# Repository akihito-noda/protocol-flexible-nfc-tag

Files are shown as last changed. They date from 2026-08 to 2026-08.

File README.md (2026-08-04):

# Protocol-Flexible Custom NFC Sensor Tag

Hardware design files and firmware for the sensor tag described in:

> R. Maeda and A. Noda, "Protocol-Flexible Custom NFC for Wire-Free Wearable Sensor Networks,"
> *IEEE Sensors Letters*, under review.

An NFC sensor tag whose communication protocol is defined in software rather than fixed in a
transponder IC. This repository holds the material that does not fit within the four-page limit of
the Letter. It is not a build guide; the schematic and the sources are the primary record, and
anything not stated here can be read from them.

This is a research prototype for protocol exploration. It is not optimized for power
(17 mW, battery-powered) and it does not implement, and is not interoperable with, ISO/IEC 14443.

## Contents

```
hardware/
  schematic/tag-schematic.pdf   Tag schematic, with component values
  gerber/                       Gerber and drill files for the tag PCB
firmware/
  tag_sensor/                   Tag firmware (Arduino sketch, ATmega328P)
  reader/                       Reader firmware (Arduino sketch, STM32duino)
```

No separate bill of materials is provided; the parts are on the schematic.

## Reader hardware

Commercial boards, used as supplied, so no design files are included here:

- **X-NUCLEO-NFC08A1** (STMicroelectronics), carrying an **ST25R3916B** NFC reader IC and a
  47 mm x 34 mm four-turn 13.56 MHz printed antenna
- **NUCLEO-L476RG** (STMicroelectronics) as the host

The ST25R3916B was selected for its transparent mode, which bypasses the on-chip framing and coding
and gives the host microcontroller access to the baseband signals. Its automatic antenna tuning is
not used, and apart from the register writes in `reader.ino` the IC runs with its default settings.

## Build environment

Arduino IDE 2.3.10.

**Reader.** STM32duino core 2.12.0, board Nucleo-64 with part number Nucleo L476RG, upload by mass
storage. `U(S)ART support` must be set to *Enabled (no generic 'Serial')*, because the sketch
declares its own `HardwareSerial` instances.

**Tag.** The ATmega328P runs from its internal 8 MHz RC oscillator, so the stock Arduino board list
does not cover it. We used the *ATmega328 on a breadboard (8 MHz internal clock)* definition that
Arduino distributes as `breadboard-1-6-x.zip`
(<https://www.arduino.cc/en/uploads/Tutorial/breadboard-1-6-x.zip>, described at
<https://docs.arduino.cc/built-in-examples/arduino-isp/ArduinoToBreadboard/>). It is not
redistributed here, since its licence is not stated. The instructions on that page are for an older
IDE; with IDE 2.x we had to extract the archive into the Arduino data directory
(`%LOCALAPPDATA%\Arduino15\packages\` on Windows) rather than the sketchbook `hardware` folder.
Tested on Windows only.

`TAG_NUM` in `tag_sensor.ino` sets the address of each tag and must differ between them.

## Protocol

| | |
| --- | --- |
| Carrier | 13.56 MHz |
| Reader to tag | 10% ASK |
| Tag to reader | Load modulation, on-off keying on a 1 MHz subcarrier |
| Line code | Return-to-zero, generated by expanding UART output |
| UART baud rate | 100 kbaud (50 kbaud effective after RZ) |
| Request frame | 2 bytes |
| Reply frame | 3 acceleration bytes and 1 CRC byte |
| Slot time | 1.5 ms per tag |
| Polling rate | 222 Hz per tag with three tags |

`ERR_COUNT` in `reader.ino` selects the mode: when defined, the sketch counts failed polls per tag
instead of printing samples. It is set to 1000, the value used for the packet-error-rate
measurements in the paper.

## Meander coil

400 mm x 260 mm, copper tape on a fabric substrate, divided into six sections by series capacitors.
Measured with the loop opened: L = 1.7 uH, and with 82.5 pF in series the resonance is at 13.44 MHz
with |Z11| = 6.45 ohm, Q = 22.3 and a -3 dB bandwidth of 604 kHz. The coil follows prior work cited
in the paper and is not a contribution of this repository.

## License

MIT License, see `LICENSE`. This covers the whole repository, including the hardware design files.

## Citing

See `CITATION.cff`. Please cite the Letter rather than this repository.

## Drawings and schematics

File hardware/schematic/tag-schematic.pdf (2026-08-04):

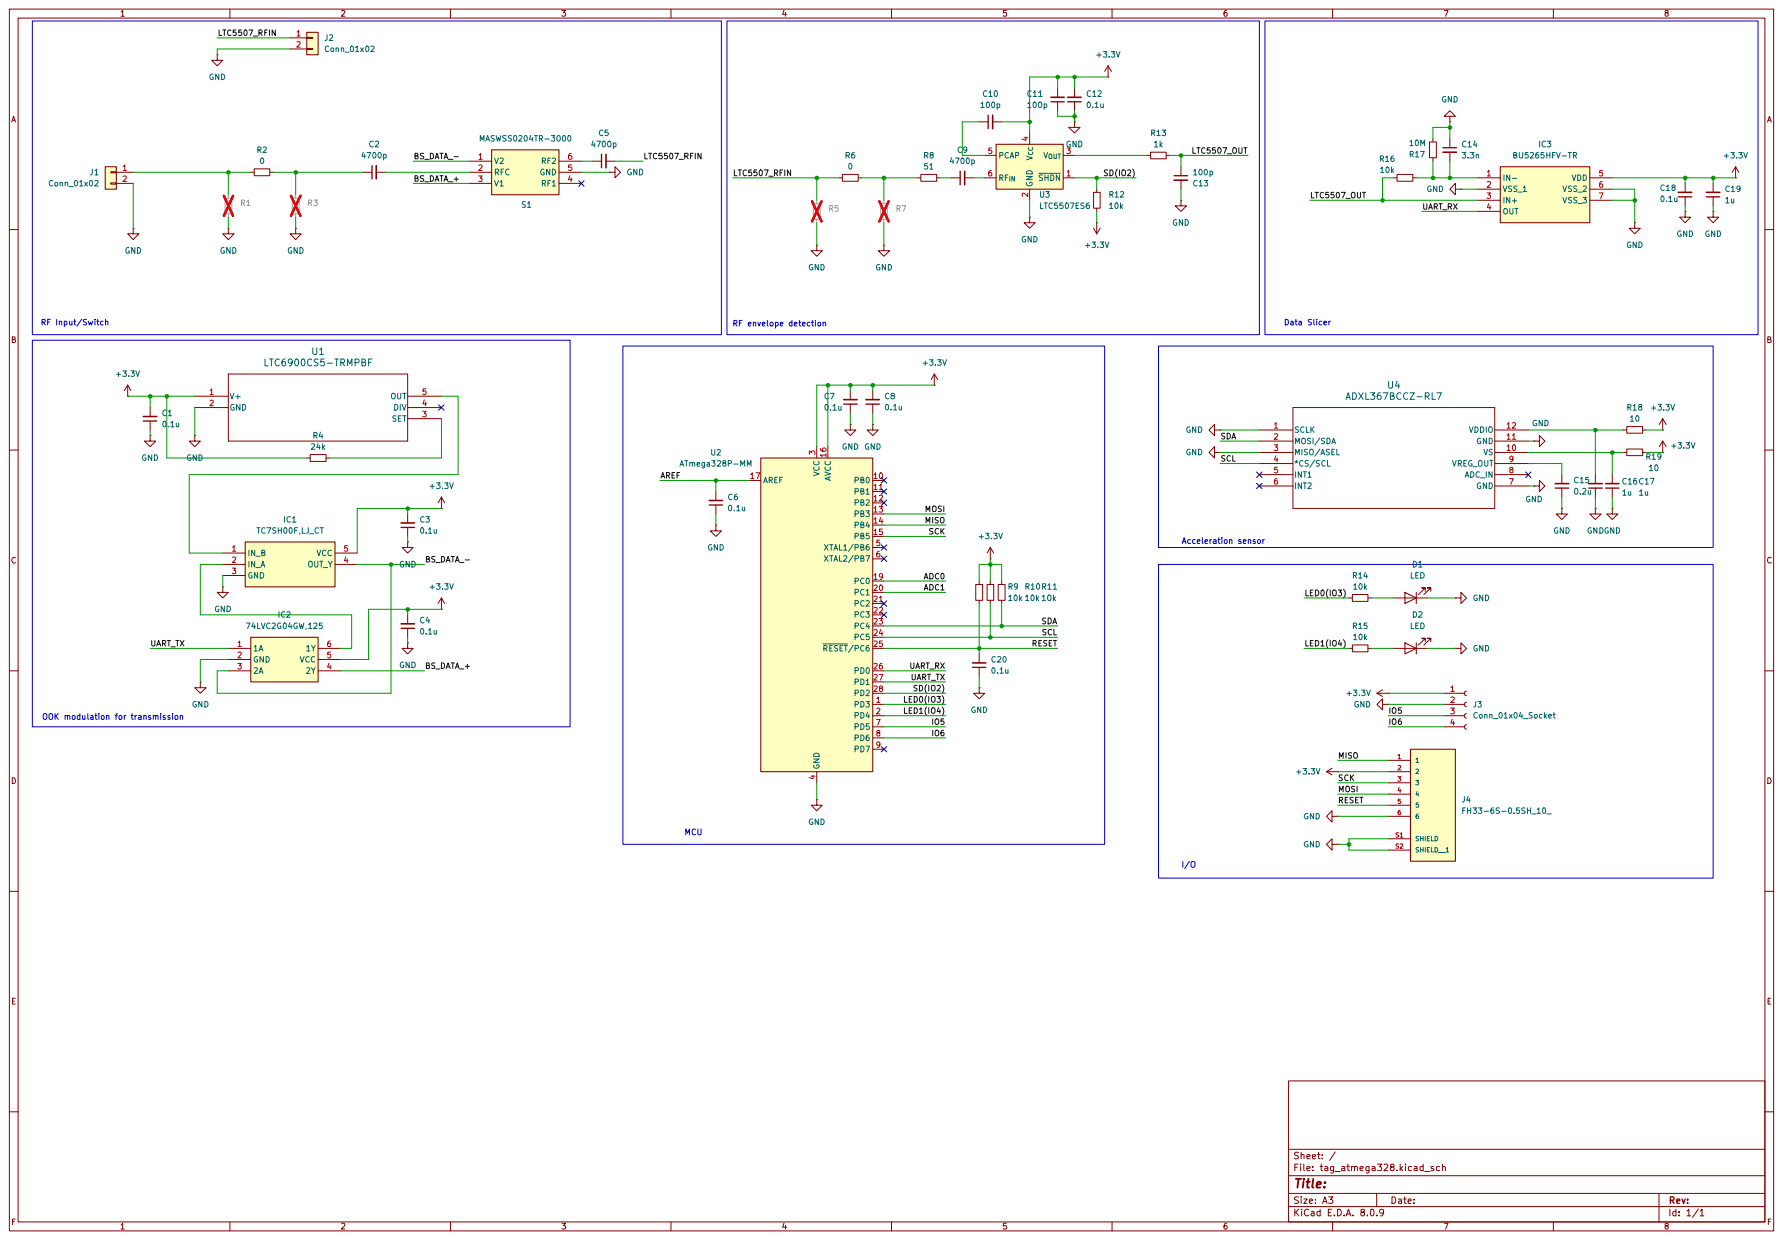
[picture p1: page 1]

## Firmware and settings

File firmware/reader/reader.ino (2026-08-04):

#include <SPI.h>

#define MCU_LED_1 PA1
#define PIN_SS    10
#define PIN_MOSI  11
#define PIN_MISO  12
#define PIN_SCK   13

#define TAG_NUM   3

#define ERR_COUNT 1000   // number of polls per tag used for the error-rate measurements reported in the paper

HardwareSerial nfc_Serial(PB11, PB10);
HardwareSerial stlink_Serial(PA3, PA2);
SPISettings spiSettings(4000000, MSBFIRST, SPI_MODE1);

void write_cmd(uint8_t cmd){
  cmd = 0b11000000 | (0b00111111 & cmd);

  digitalWrite(PIN_SS, LOW);

  SPI.transfer(cmd);

  digitalWrite(PIN_SS, HIGH);
}

void write_register(uint8_t reg, uint8_t data){
  reg = 0b00000000 | (0b00111111 & reg);
  digitalWrite(PIN_SS, LOW);

  SPI.transfer(reg);
  SPI.transfer(data);

  digitalWrite(PIN_SS, HIGH);
}

void setup(){
  stlink_Serial.begin(1000 * 1000);
  pinMode(MCU_LED_1, OUTPUT);

  // UART pins High-Z
  pinMode(PB10, INPUT);
  pinMode(PB11, INPUT);

  SPI.begin();
  SPI.beginTransaction(spiSettings);
  pinMode(PIN_SS, OUTPUT);
  digitalWrite(PIN_SS, HIGH);
  
  // NFC setup
  write_register(0x00, 0b00000101);   // Enable antenna drive, 13.56MHz output frequency, MCU_CLK off
  write_register(0x01, 0b00000000);   // VDD5V amrefV_{dd_rf}
  write_cmd(0xd6);    // Adjust Regulators
  write_cmd(0xc0);    // Set Default
  write_cmd(0xea);    // Trigger RC calibration
  write_register(0x03, 0b00001100);   // AM modulation
  write_register(0x28, 0b00100000);   // AM modulation index 10%, Output driver resistance 1 Ohm
  write_register(0x02, 0b11001000);   // Enable oscillator/regulator, Enable transmission
  write_register(0x0b, 0b00010100);   // Filter settings
  write_register(0x0c, 0b00001000);   // Demodulation method
  write_register(0x0d, 0b11100000);
  write_cmd(0xd5);    // Reset RX Gain
  write_cmd(0xdc);    // Enter Transparent Mode
  SPI.end();

  // Initialize communication UART
  nfc_Serial.setTxInvert();
  nfc_Serial.setRxInvert();
  nfc_Serial.begin(100 * 1000);
  uart_rz_init();
}

void loop(){
  for (uint8_t tag_num = 0; tag_num < TAG_NUM; tag_num++){
    // Send request every 20ms per tag
    uint32_t start_time = micros();

    // Send request to T0 tag
    uart_rz_write('T');
    uart_rz_write('0' + tag_num);
    nfc_Serial.flush();
    int uart_len = nfc_Serial.available();
    for (int i = 0; i < uart_len; i++){
      nfc_Serial.read();
    }
    delay(1);

    // Process response from A
    int rx_status = 0;
    int8_t rx_data[4] = {0};
    digitalWrite(MCU_LED_1, HIGH);
    while (micros() - start_time < 1400){
      rx_status += uart_rz_read((uint8_t*)&rx_data[rx_status]);
      if (rx_status >= 4) break;
    }

    // Measure error rate
    // Calculate error rate from the last ERR_COUNT data points
    #ifdef ERR_COUNT
    static uint32_t req_count = 0;
    static uint32_t err_count[TAG_NUM] = {0};
    if (tag_num == TAG_NUM - 1){
      req_count++;
      if (req_count >= ERR_COUNT) {
        for (int i = 0; i < TAG_NUM; i++){
          stlink_Serial.print(err_count[i]);
          stlink_Serial.print(',');
        }
        stlink_Serial.print(ERR_COUNT);
        stlink_Serial.print('\n');
        stlink_Serial.flush();
        req_count = 0;
        for (int i = 0; i < TAG_NUM; i++) err_count[i] = 0;
      }
    }
    #endif

    // If response received, send to USB serial
    if (rx_status >= 4 && calc_crc8(rx_data, 3) == (uint8_t)rx_data[3]){
      #ifndef ERR_COUNT
      stlink_Serial.print(start_time);
      stlink_Serial.print(",T");
      stlink_Serial.print(tag_num);
      for (int i = 0; i < 3; i++){
        stlink_Serial.print(',');
        stlink_Serial.print(rx_data[i]);
      }
      stlink_Serial.print('\n');
      stlink_Serial.flush();
      #endif
    }
    else{
      #ifdef ERR_COUNT
      err_count[tag_num]++;
      #endif
    }

    // Wait for the next transmission request
    while (micros() - start_time < 1500) delayMicroseconds(10);
  }
}

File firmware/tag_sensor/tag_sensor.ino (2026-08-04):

#define TAG_NUM 0

void setup() {
  // put your setup code here, to run once:
  Serial.begin(100000);
  pinMode(3, OUTPUT);
  
  // Initialize ADXL367
  adxl367_init_acceleration_8bit();
  
  uart_rz_init();
}

void loop() {
  uint8_t rx_data;
  static int8_t acceleration_data[4];
  while (!uart_rz_read(&rx_data));
  if (rx_data != 'T') return;

  while (!uart_rz_read(&rx_data));
  if (rx_data != '0' + TAG_NUM) return;
  
  uart_rz_write(acceleration_data[0]);
  uart_rz_write(acceleration_data[1]);
  uart_rz_write(acceleration_data[2]);
  uart_rz_write(acceleration_data[3]);

  adxl367_acceleration_read_8bit(acceleration_data);

  // Calculate CRC
  acceleration_data[3] = calc_crc8(acceleration_data, 3);
}
